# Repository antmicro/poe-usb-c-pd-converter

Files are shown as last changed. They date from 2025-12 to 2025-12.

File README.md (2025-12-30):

# Power over Ethernet to USB-C Power Delivery Adapter 

Copyright (c) 2024-2025 [Antmicro](https://www.antmicro.com)



## Overview

This project contains open hardware PCB design files for an adapter that splits a Power-over-Ethernet (PoE) capable RJ45 interface port into a USB-C Power Delivery (PD) port and an Ethernet RJ45 port. 
It negotiates power from PoE Power Sourcing Equipment (PSE) such as a PoE switch or a PoE injector.
For the USB-C connection, the board serves as an Upstream Facing Port (UFP) power source.
The USB-C port can be used for reading current and voltage negotiated for the PD.

## Key features

* RJ45 input port for data and PoE++ (IEEE 802.3bt)
* RJ45 output port passing raw Ethernet data from the input port
* USB-C regular connector with Power Delivery feature and USB data downstream
* Automatic input power negotiation (up to 71W) from PSE
* Externally programmable flash memory
* Programmable USB Power Delivery power profiles up to 60W
* On-board VBUS voltage, current and power measurement circuitry
* On-board external fan driver with a 4-pin standard receptacle
* 112 x 56 mm (4.4 x 2.2 inch) mechanical outline

## Project structure

The main directory contains KiCad PCB design files, a LICENSE and a README.
The remaining files are stored in the following directories:
* `img` - contains graphics for this README

## License
 
This project is published under the [Apache-2.0](LICENSE) license.

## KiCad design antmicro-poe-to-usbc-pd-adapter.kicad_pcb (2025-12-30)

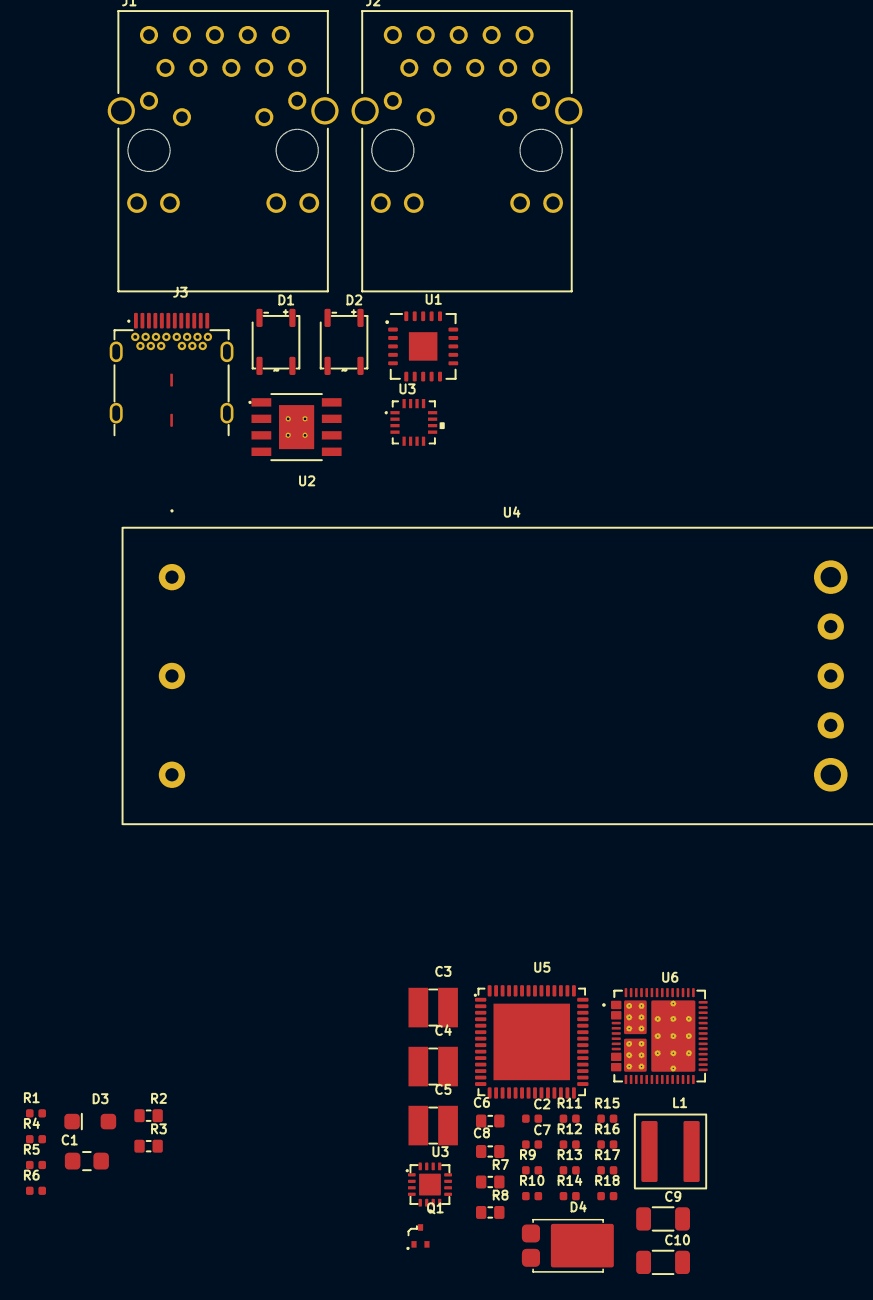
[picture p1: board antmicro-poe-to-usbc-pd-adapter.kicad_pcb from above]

Board: 2 copper layers, 44 parts (0 on the bottom side), 49 nets, no tracks yet.

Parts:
C1: C_100n_100V_0805; C_0805_2012Metric
C2: C_10n_50V_X7R_0402; C_0402_1005Metric
C3: C_4u7_1210_100V; C_1210_3225Metric
C4, C5: C_2u2_1210; C_1210_3225Metric
C6, C8: C_100n_100V_X7R_0603; C_0603_1608Metric
C7: C_3n3_0402; C_0402_1005Metric
C9, C10: C_47u_25V_1206; C_1206_3216Metric
D1, D2: CD-MMBL110S; DFN3538
D3: PTVS58VS1UR,115; D_SOD-123F
D4: PDS760; PowerDI5
J1, J2: Bus_RJ45_5-2337992-8; RJ45_X-2337992-8_Horizontal
J3: USB-C_WE_632723300011; USB-C_Receptacle_WE_632723300011
L1: L_6u8_6.1A_MPS-MPL-AL5050; L_MPS-MPL-AL5050
Q1: PJE138K; SOT-523
R1: R_24k9_0402; R_0402_1005Metric
R2: R_63R4_0603; R_0603_1608Metric
R3: R_90R9_0603; R_0603_1608Metric
R4: R_1k3_0402; R_0402_1005Metric
R5: R_0R_0402; R_0402_1005Metric
R6: R_49k9_0402; R_0402_1005Metric
R7, R8: R_0R_0603; R_0603_1608Metric
R9: R_27k_0402; R_0402_1005Metric
R10: R_470k_0402; R_0402_1005Metric
R11: R_100k_0402; R_0402_1005Metric
R12: R_10k_0402; R_0402_1005Metric
R13: R_200k_0402; R_0402_1005Metric
R14: R_7k68_0402; R_0402_1005Metric
R15, R16: R_2k7_0402; R_0402_1005Metric
R17: R_4k7_0402; R_0402_1005Metric
R18: R_17k4_0402; R_0402_1005Metric
U1: TPS2372-3RGWR; VQFN-20_5x5x1mm_P0.65mm
U2: LV14540DDAR; SOIC-8-1EP_3.9x4.9x1.75mm_P1.27mm_EP_vias
U3: INA230AIRGTR; VQFN-16-1EP_3x3mm_P0.5mm_EP1.68x1.68mm
U3#2: STUSB4710AQ1TR; QFN-16_3x3mm_P0.5mm
U4: IEA48003A280V-001-R
U5: FT4232H_VQFN; QFN-56-1EP_8x8mm_P0.5mm
U6: TPS65988DHRSHR; IC_TPS65987DDHRSHR

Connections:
/CLSA: R2.2, U1.3 (CLSA)
/CLSB: R3.2, U1.6 (CLSB)
/P1: J1.1, J2.1
/P2: J1.2, J2.2
/P3: J1.3, J2.3
/P4: J1.4, J2.4
/P5: J1.5, J2.5
/P6: J1.6, J2.6
/P7: J1.7, J2.7
/P8: J1.8, J2.8
/P9: J1.9, J2.9
/P10: J1.10, J2.10
/POE.VC1: D1.3, J1.11 (VC1)
/POE.VC2: D1.4, J1.12 (VC2)
/POE.VC3: D2.4, J1.13 (VC3)
/POE.VC4: D2.3, J1.14 (VC4)
/VDD: C1.2, D1.2, D2.2, R1.1, R10.2, U1.1 (VDD), U4.1 (VIN+)
/VSS: C1.1, D1.1, D2.1, R2.1, R3.1, R4.1, R5.2, R6.1, U1.4 (VSSA), U1.5 (VSSB)
GND: C2.1, C3.1, C4.1, C5.1, C6.1, C7.1, C9.1, C10.1, D4.2 (A), R8.1, R9.1, R18.1, U2.7 (GND), U2.9 (GND), U4.4 (VOUT-), U4.5 (SENSE-)
GNDD: Q1.2 (S), R11.1, U1.11 (RTNA), U1.12 (RTNB), U4.3 (VIN-)
unnamed: C9.2, C10.2, L1.2, R13.2
unnamed: C8.1, D4.1 (C), L1.1, U2.8 (SW)
unnamed: J1.19 (SHIELD), J1.20 (SHIELD)
unnamed: J2.19 (SHIELD), J2.20 (SHIELD)
unnamed: J3.A1 (GND), J3.A12 (GND), J3.B1 (GND), J3.B12 (GND)
unnamed: Q1.3 (D), U4.2 (!ON)
unnamed: Q1.1 (G), R10.1, R11.2, R12.1
unnamed: R14.1, R15.2
unnamed: R15.1, R16.2
unnamed: R16.1, R17.2
unnamed: R17.1, R18.2
unnamed: R4.2, U1.8 (AMPS_CTL)
unnamed: R1.2, U1.2 (DEN)
unnamed: R5.1, U1.9 (MPS_DUTY)
unnamed: R12.2, U1.13 (PG)
unnamed: R6.2, U1.7 (REF)
unnamed: C8.2, U2.1 (BOOT)
unnamed: C3.2, C4.2, C5.2, C6.2, R7.1, U2.2 (VIN), U2.3 (EN), U4.7 (SENSE+), U4.8 (VOUT+)
unnamed: R13.1, R14.2, U2.5 (FB)
unnamed: R9.2, U2.4 (RT)
unnamed: C7.2, U2.6 (SS)
unnamed: C2.2, R7.2, R8.2, U4.6 (TRIM)
unnamed: U5.21 (GND), U5.41 (GND), U5.45 (GND), U5.57 (GND)
unnamed: U5.16 (V_{CCIO}), U5.36 (V_{CCIO}), U5.50 (V_{CCIO})
unnamed: U5.2 (V_{CORE}), U5.31 (V_{CORE})
unnamed: U6.20 (GND), U6.51 (GND)
unnamed: U6.8 (DRAIN1), U6.15 (DRAIN1), U6.19 (DRAIN1), U6.58 (DRAIN1)
unnamed: U6.7 (DRAIN2), U6.52 (DRAIN2), U6.56 (DRAIN2), U6.57 (DRAIN2)
VBUS: J3.A4 (VBUS), J3.A9 (VBUS), J3.B4 (VBUS), J3.B9 (VBUS)

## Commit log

2025-12-30 [#62182] Create schematic place components route TPS2372
    [antmicro-poe-to-usbc-pd-adapter.kicad_pcb, antmicro-poe-to-usbc-pd-adapter.kicad_sch]
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2025-12-30 [#62182] Add INA230, remove STUSB4710
    [antmicro-poe-to-usbc-pd-adapter.kicad_sch]
2025-12-30 [#62182] Major changes in schematic
    Add TPS65987D
    Add FT4232H
    Add 3v3 buck
    Connect components
    [antmicro-poe-to-usbc-pd-adapter.kicad_pcb, antmicro-poe-to-usbc-pd-adapter.kicad_sch]
2025-12-30 [#62182] Connect INA230
    This is first commit after Meeting #62027
    [antmicro-poe-to-usbc-pd-adapter.kicad_sch]
2025-12-30 [#62182] Change passives, correct gnd
    [antmicro-poe-to-usbc-pd-adapter.kicad_sch]
2025-12-30 [#62182] Add shunt resistor for INA230
    [antmicro-poe-to-usbc-pd-adapter.kicad_sch]
2025-12-30 [#62182] Place components PCB
    [antmicro-poe-to-usbc-pd-adapter.kicad_sch]
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2025-12-30 [#62182] Update resistor fields
    [antmicro-poe-to-usbc-pd-adapter.kicad_sch]
2025-12-30 [#62182] Tie VBUS1 and VBUS2
    [antmicro-poe-to-usbc-pd-adapter.kicad_sch]
2025-12-30 [#62182] Add mux to flash
    [antmicro-poe-to-usbc-pd-adapter.kicad_sch]
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2025-12-30 [#62623] Improved schematic, added hierarchy
    [3V3_buck.kicad_sch, ETH_connectors.kicad_sch, FTDI.kicad_sch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]
2025-12-30 [#62623] Improve schematic, change 3V3 buck inductor, correct SPI, add testpoint
    [3V3_buck.kicad_sch, ETH_connectors.kicad_sch, FTDI.kicad_sch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]
2025-12-30 [#62623] Change hierarchy implementation
    [3V3_buck.kicad_sch, FTDI.kicad_sch, Memory.kicad_sch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]
2025-12-30 [#62623] Minor graphical changes
    [FTDI.kicad_sch, antmicro-poe-to-usbc-pd-adapter.kicad_sch, main_power_stage.kicad_sch]
2025-12-30 [#62623] PCB initial placement
    [PoE_supply.kicad_sch, USBPD_output.kicad_sch, main_power_stage.kicad_sch]
2025-12-30 [#62623] Minor changes in placement/schematic
    [USBPD_output.kicad_sch]
2025-12-30 [#62623] Add planes to variable buck
    [PoE_supply.kicad_sch]
2025-12-30 [#62623] Las commit before major change in placement
    [PoE_supply.kicad_sch, USBPD_output.kicad_sch, main_power_stage.kicad_sch]
2025-12-30 [#62835] Change dcdc placement, change IC's placement
    [PoE_supply.kicad_sch, USBPD_output.kicad_sch, antmicro-poe-to-usbc-pd-adapter.kicad_sch]
2025-12-30 [#62835] Change R30 to geneerate CI
    [3V3_buck.kicad_sch, ETH_connectors.kicad_sch, FTDI.kicad_sch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]
2025-12-30 [#62835] Route ETH differential pairs
    [FTDI.kicad_sch, PoE_supply.kicad_sch, USBPD_output.kicad_sch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]
2025-12-30 [#62835] Start PWR plane placement
    [main_power_stage.kicad_sch]
2025-12-30 [#62835] Start routing low speed signals
    [PoE_supply.kicad_sch]
2025-12-30 [#62835] Add esd protection for usb, add pwr planes, route LS signals
    [USBPD_output.kicad_sch]
2025-12-30 [#62835] Tackle DRC problems, change vias size
    [USBPD_output.kicad_sch]
2025-12-30 [#62835] Tacle ERC problems, add PWR flags
    [FTDI.kicad_sch, PoE_supply.kicad_sch, USBPD_output.kicad_sch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]
2025-12-30 [#62835] Add vias, second GND plane, GNDD plane, lower INA IC, minor changes
    [FTDI.kicad_sch, PoE_supply.kicad_sch]
2025-12-30 [#62835] Add filtering capacitors to FTDI
    [FTDI.kicad_sch]
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2025-12-30 [#62835] PoE to USB-C PD Review Rev.1.0.0 correct points 1,3,4,6,7,11
    [FTDI.kicad_sch, PoE_supply.kicad_sch, USBPD_output.kicad_sch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]
2025-12-30 [#62835] Add ETH receptacle diode steering
    [PoE_supply.kicad_sch, main_power_stage.kicad_sch]
2025-12-30 [#62835] Change L3 3V3 buck and divider, to 5V dcdc buck
    [main_power_stage.kicad_sch]
2025-12-30 [#62835] Add 3V3 LDO
    [main_power_stage.kicad_sch]
2025-12-30 [#62835] Add 3V3 LDO to PCB, place CBUS capacitors, change 5V buck layout
    [PoE_supply.kicad_sch, USBPD_output.kicad_sch, main_power_stage.kicad_sch]
2025-12-30 [#62835] Change IEA48003A280V-001-R input capacitors
    [PoE_supply.kicad_sch]
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2025-12-30 [#63274] Add heatsink, start moving components to make space
    [main_power_stage.kicad_sch]
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2025-12-30 [#63274] Add heatsink, clear DRC
    [FTDI.kicad_sch]
2025-12-30 [#63274] Add status LEDs for PoE controller
    [PoE_supply.kicad_sch]
2025-12-30 [#63274] Change TPS65987 feedback for DCDC gpio pinout
    [USBPD_output.kicad_sch, main_power_stage.kicad_sch]
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2025-12-30 [#63274] Add PSE type marking
    [PoE_supply.kicad_sch]
2025-12-30 [#63274] Add testpoints, improve silcscreen
    [PoE_supply.kicad_sch, USBPD_output.kicad_sch, antmicro-poe-to-usbc-pd-adapter.kicad_sch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]
2025-12-30 [#63274] Prepare for visualization and fabhouse
    [main_power_stage.kicad_sch]
2025-12-30 [#63274] Add optocouplers for ETH diode, TPS65987D HRESET
    [PoE_supply.kicad_sch, antmicro-poe-to-usbc-pd-adapter.kicad_sch, main_power_stage.kicad_sch]
2025-12-30 [#63274] Remove one optocoupler, add components to PCB, route PCB
    [FTDI.kicad_sch, PoE_supply.kicad_sch, antmicro-poe-to-usbc-pd-adapter.kicad_sch]
2025-12-30 [#63274] Change transistors to BS5123
    [PoE_supply.kicad_sch]
2025-12-30 [#63274] Placed transistors on PCB, routed, cleared DRC
    [PoE_supply.kicad_sch]
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2025-12-30 [#63274] Update symbol R79 and R10 for CI
    [PoE_supply.kicad_sch]
2025-12-30 [#63274] Again change R10
    [PoE_supply.kicad_sch]
2025-12-30 [#63274] Update R28 and R31
    [main_power_stage.kicad_sch]
2025-12-30 [#63798] Change SOIC-8-1EP_3.9x4.9x1.75mm_P1.27mm for the same one but without EP
    [main_power_stage.kicad_sch]
2025-12-30 [#64013] Prepare production fixes
    [FTDI.kicad_sch, PoE_supply.kicad_sch, USBPD_output.kicad_sch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]
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2025-12-30 [#66725] Implement changes from review for rev 1.1.0
    [3V3_buck.kicad_sch, ETH_connectors.kicad_sch, FTDI.kicad_sch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]
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

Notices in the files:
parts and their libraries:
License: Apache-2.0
